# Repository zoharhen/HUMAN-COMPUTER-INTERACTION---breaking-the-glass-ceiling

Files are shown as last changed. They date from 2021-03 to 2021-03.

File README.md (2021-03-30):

# Breaking the glass ceiling - final project for 'Introduction to human computer interaction' (HCI) course (67298):
Shirley Haimoff and I had designed and programmed a human-computer interaction using Arduino, 3D printing, Rhino and Grasshopper. 
The project combines gesture recognition using an accelerometer and a computer game challenging the player to break the glass ceiling. 

Watch the video (https://user-images.githubusercontent.com/49272962/113001302-5949a100-9179-11eb-92e5-f8f246e2bbed.mp4)

## Contributions

All contributions are welcome!
Please feel free to post questions, recommendations, ideas, bugs by create [new issue](https://github.com/zoharhen/HUMAN-COMPUTER-INTERACTION---breaking-the-glass-ceiling/issues/new) following the template or if you want create directly [new pull request](https://github.com/zoharhen/HUMAN-COMPUTER-INTERACTION---breaking-the-glass-ceiling/compare).

## Authors

<a href="https://www.linkedin.com/in/zohar-hen-3477a7177/" target="_blank">
  
</a>

**Zohar Hen**



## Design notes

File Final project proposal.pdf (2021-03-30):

## Ex7 – Shirley Haimoff (206145245) and Zohar Hen (206092991)

Final project proposal:

We decided to imitate breaking a glass ceiling, in a way that will demonstrate the hard work and journey this should take.

For this purpose, we chose the physical agent to be a real-size hammer, printed as two separated parts - a hammerhead and a handle, connected with an axis, so the hammerhead will be straight only when the object is in a horizontal orientation, and the flat side of the hammerhead is pointed to the ceiling (see physical agent in illustration below).

The virtual agent, shows a visualization of a glass ceiling, which will be projected on the ceiling using a projector, implying to the user in which direction the hammer should be pointed. Despite the above, it still might take a while until the user gets the correct direction to use hammer –which is fine because even in real life it is a difficult and an unclear process. Therefor the user may take time to understand the right way to do it.

Using the accelerometer, hiding inside the hammer handle, we will recognize 4 different kinds of gestures:
a. Static state (default, when there are no gesture) – the night sky behind the glass ceiling flickers gently, like shining stars. We chose to present the night sky not only because the glass ceiling will be much clearer this way – but also because the shining stars represent dreams and goals one wants to achieve by breaking the glass ceiling.
b. Simple gesture 1 - striking the hammer (when the hammer is in a horizontal orientation, and the flat side of the hammerhead is pointing to the ceiling): There are ~8 steps until the celling is completely broken, with each knock the number of glass fragments presented by the virtual agent will increased.
c. Simple gesture 2: sliding the hammer in order to remove a nail (same orientation as in B but using the other side of the hammerhead): When performing this gesture, the currently broken fragments will slide from the user preview, and a newly completed celling will be presented instead.
d. Complex moves – after a sequence of ~8 iterations of gesture b (striking the hammer), the night sky behind the glass ceiling will be replaced with day-light, notifying the user that mission was accomplish.

### 1. Technical drawing of the electronic circuit:

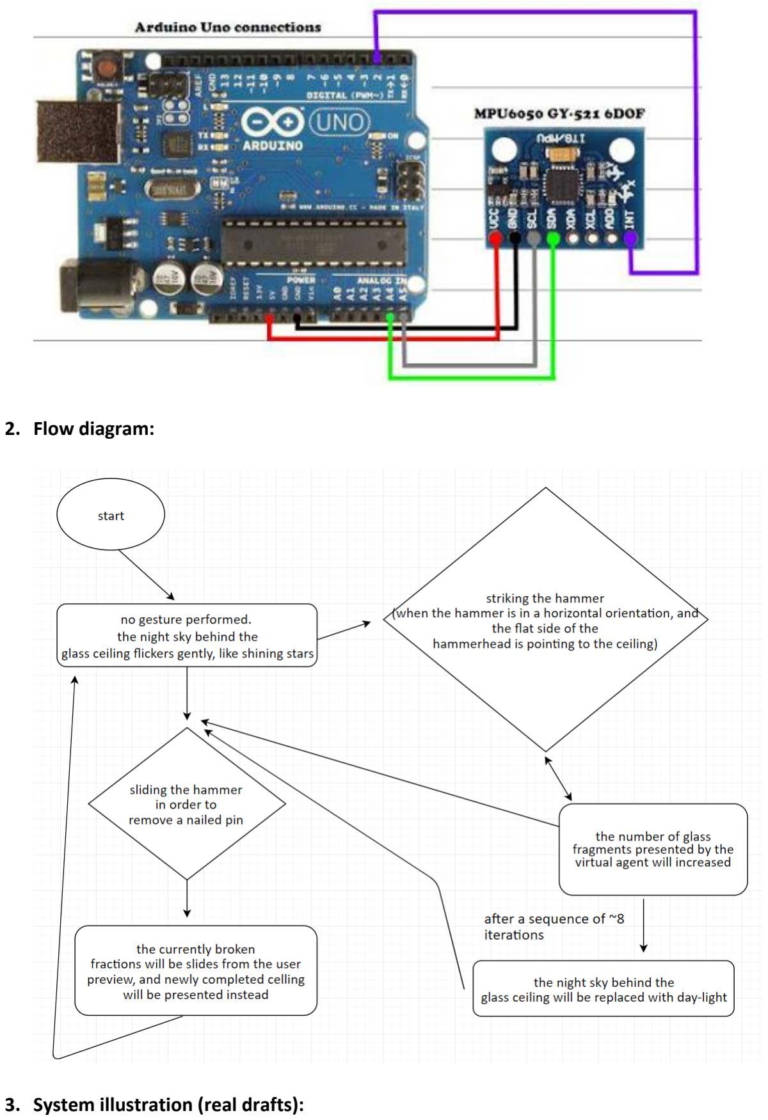
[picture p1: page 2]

### 2. Flow diagram:

### 3. System illustration (real drafts):

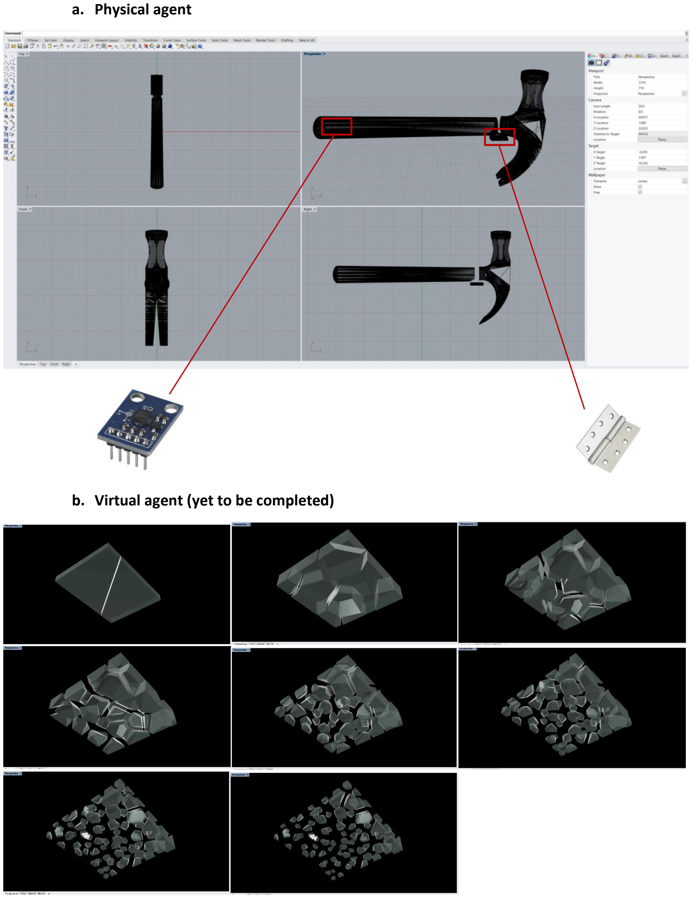
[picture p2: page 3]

a. Physical agent
b. Virtual agent (yet to be completed)

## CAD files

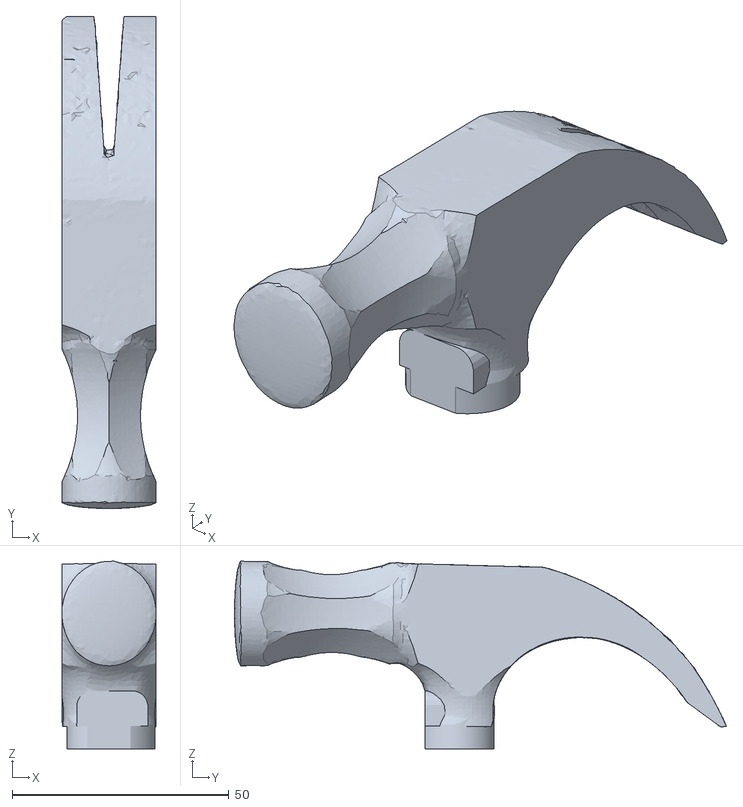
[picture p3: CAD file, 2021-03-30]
head.stl
21.8 x 113.6 x 43.4

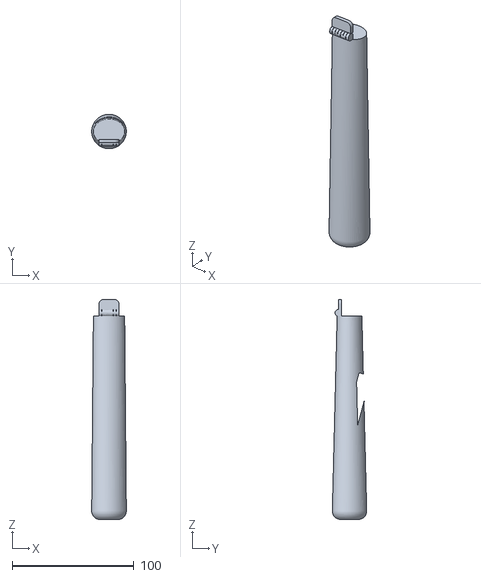
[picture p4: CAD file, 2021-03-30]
handle.stl
28.4 x 28.2 x 180.3

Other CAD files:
virtualAgent.3dm

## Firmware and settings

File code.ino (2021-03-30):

#include<Wire.h>
#define NOTHING 0
#define KNOCK 1
#define SLIDE 2
#define MAX_KNOCK 3
#define RESET_MAX_KNOCK 4

const int MIN_GLASS = 2;
const int MAX_GLASS = 100;
const int VERY_LONG_DELAY = 100;
const int LONG_DELAY = 50;
const int SHORT_DELAY = 25;
int knockCounter;

const int filterSize = 31;
float hpf[filterSize] = {0.0561, -0.149, 0.1263, 0.0152, -0.069, -0.026, 0.0447, 0.0433, -0.023, -0.062, -0.010, 0.0766, 0.0716, -0.087, -0.306, 0.5904, -0.306, -0.087, 0.0716, 0.0766, -0.010, -0.062, -0.023, 0.0433, 0.0447, -0.026, -0.069, 0.0152, 0.1263, -0.149, 0.0561};
float lpf[filterSize] = {-0.025, -0.000, 0.0014, 0.0041, 0.0078, 0.0125, 0.0179, 0.0238, 0.0301, 0.0364, 0.0425, 0.0479, 0.0525, 0.0559, 0.0581, 0.0588, 0.0581, 0.0559, 0.0525, 0.0479, 0.0425, 0.0364, 0.0301, 0.0238, 0.0179, 0.0125, 0.0078, 0.0041, 0.0014, -0.000, -0.025};
float cyclicBuffer[filterSize];
float lpfConvolution = 0.0;
float hpfConvolution = 0.0;
float lpfValue = 0.0;
float hpfValue = 0.0;
float alpha = 0.5;
float lpfThreshold = 12000.0;
float hpfThreshold = 2000.0;
const int MPU6050_addr=0x68;
int16_t AccX;
int16_t AccY;
int16_t AccZ;
int curIndex = 0;
int lastGesture = NOTHING;

void setup() {
  for (int i = 0; i < filterSize; i++)
  {
    cyclicBuffer[i] = 1; 
  }
  initMpu();
  empty_loop(50);
}

/*
 * a method to init MPU
 */
void initMpu()
{
  Wire.begin();
  Wire.beginTransmission(MPU6050_addr);
  Wire.write(0x6B);
  Wire.write(0);
  Wire.endTransmission(true);
  Serial.begin(9600);
  knockCounter = 0;
}

void empty_loop(int num_of_times)
{
  for (int i = 0; i < num_of_times; i++)
  {
    readMPU();
    cyclicBuffer[curIndex] = (float)AccZ;
  
    // convolution:
    lpfConvolution = 0;
    hpfConvolution = 0;
    for (int j = 0; j < filterSize; j++ )
    {
      lpfConvolution += cyclicBuffer[(curIndex - j + filterSize) % filterSize] * lpf[j];
      hpfConvolution += cyclicBuffer[(curIndex - j + filterSize) % filterSize] * hpf[j];
    }
    // running average:
    lpfValue = alpha * abs(lpfConvolution) + (1.0 - alpha) * lpfValue;
    hpfValue = alpha * abs(hpfConvolution) + (1.0 - alpha) * hpfValue;

    curIndex = (curIndex + 1) % filterSize;
    delay(25);
  }

}

void loop() {
  readMPU();
  cyclicBuffer[curIndex] = (float)AccZ;

  // convolution:
  lpfConvolution = 0;
  hpfConvolution = 0;
  for (int j = 0; j < filterSize; j++ )
  {
    lpfConvolution += cyclicBuffer[(curIndex - j + filterSize) % filterSize] * lpf[j];
    hpfConvolution += cyclicBuffer[(curIndex - j + filterSize) % filterSize] * hpf[j];
  }
  // running average:
  lpfValue = alpha * abs(lpfConvolution) + (1.0 - alpha) * lpfValue;
  hpfValue = alpha * abs(hpfConvolution) + (1.0 - alpha) * hpfValue;
  reactToGestures();
  curIndex = (curIndex + 1) % filterSize;
  delay(30);
}


void reactToGestures()
{  
  if (lpfValue < lpfThreshold) 
  {
    int fraction = knockCounter*10;
    int modulo = knockCounter < 8 ? 10 : 4;
    for (int i = 0; i <= 360; i++)
    {
      if (i%modulo == 0) {
        fraction--; 
      }
      printHelper(SLIDE, knockCounter*10, i, fraction);
    }
    knockCounter = 0;
    empty_loop(LONG_DELAY);
    printHelper(NOTHING, MIN_GLASS, 0, MIN_GLASS);
  }
  else if (hpfValue > hpfThreshold)
  {
    handleKnock();
  }
  else if (lastGesture != NOTHING) {
      printHelper(NOTHING, knockCounter*10, 0, knockCounter*10);
  }
}

void handleKnock(){
    // note: first we need to increase counter, THEN print the updated counter
    if(knockCounter == 4) {
      knockCounter = 8;
    } else {
      knockCounter+=2;
    }
    
    if(knockCounter > 10){ 
      printHelper(MAX_KNOCK, MAX_GLASS, 0, MAX_GLASS);
      delay(20000);
      printHelper(RESET_MAX_KNOCK, MAX_GLASS, 0, MAX_GLASS);
      empty_loop(SHORT_DELAY);
      knockCounter = 0; // note: we must initialize this AFTER getting to MAX
      printHelper(NOTHING, MIN_GLASS, 0, MIN_GLASS);
      empty_loop(SHORT_DELAY);
    } else {
      printHelper(KNOCK,knockCounter*10, 0, knockCounter*10);
      empty_loop(LONG_DELAY);
      printHelper(NOTHING, knockCounter*10, 0, knockCounter*10);
    }  
}

void printHelper(int gesture, int counter, int rotate , int fraction) {
  lastGesture = gesture;
  Serial.print(gesture);
  Serial.print(",");
  Serial.print(counter);
  Serial.print(",");
  Serial.print(rotate);
  Serial.print(",");
  Serial.println(fraction);
}

/*
 * a method to read values from MPU
 */
void readMPU()
{
  Wire.beginTransmission(MPU6050_addr);
  Wire.write(0x3B);
  Wire.endTransmission(false);
  Wire.requestFrom(MPU6050_addr,14,true);
  AccX = Wire.read()<<8|Wire.read();
  AccY = Wire.read()<<8|Wire.read();
  AccZ = Wire.read()<<8|Wire.read();
}
